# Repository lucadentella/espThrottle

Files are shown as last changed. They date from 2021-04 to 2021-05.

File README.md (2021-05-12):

# espThrottle
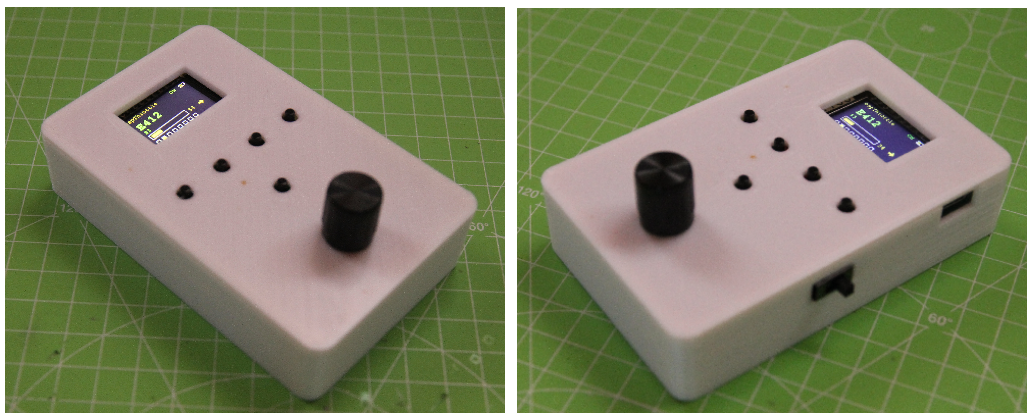
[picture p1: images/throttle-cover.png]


## Description

Portable device to control digital layouts using WiThrottle protocol.



## Features :trophy:

 - **TFT** color screen
 - **Battery** powered with built-in **USB charger**
 - Server **auto-discovery** (mDNS)
 - Configurable **favourite list** of locomotives
 - Support of JMRI **rosters**
 - Control of locomotive **speed** (128 steps) and **direction**
 - Control of 8 decoder **functions**
 - Layout **power** control
 - *Fixed address* mode

## Resources :open_file_folder:

 - [Eagle files](https://github.com/lucadentella/espThrottle/tree/main/Eagle) (schematic / PCB)
 - [Arduino firmware](https://github.com/lucadentella/espThrottle/tree/main/Arduino)
 - [3d printable case](https://github.com/lucadentella/espThrottle/tree/main/case) (STL)

## Documentation :notebook:

 - [User manual](https://github.com/lucadentella/espThrottle/tree/main/documentation/usermanual.md)
 - [Configuration manual](https://github.com/lucadentella/espThrottle/tree/main/documentation/configuration.md)
 - [How to use Roster Groups](https://github.com/lucadentella/espThrottle/tree/main/documentation/rostergroup.md)
 - [Part list](https://github.com/lucadentella/espThrottle/tree/main/documentation/partlist.md)

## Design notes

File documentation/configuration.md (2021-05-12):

# Configuration :gear:

espThrottle behavior can be configured by editing the **config.h** file:
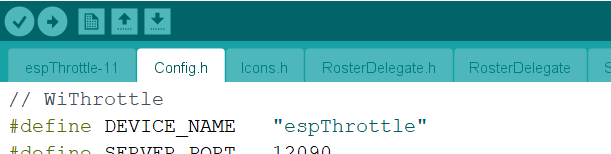
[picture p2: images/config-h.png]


## WiThrottle parameters

    #define DEVICE_NAME   "espThrottle"
    #define SERVER_PORT   12090
You can change the **device name** (i.e. the name that identifies this throttle in JMRI) and the **TCP port** the server is listening on.

## Functions

    #define ENTER_ADDRESS_ENABLED   true
    #define FAVOURITE_LIST_ENABLED  true
    #define ROSTER_LIST_ENABLED     true
    #define POWER_CONTROL_ENABLED   true
Each menu **function** can be enabled / disabled independently. 

## Fixed address mode

    #define FIXED_ADDRESS_MODE      false
The throttle can be configured in **fixed address** mode: all the menu functions (see above) are automatically disabled and the throttle controls the first locomotive of the *favourite list*.

## Speed when changing direction

    #define CHANGE_DIR_SPEED_ZERO   true
If true, when changing direction the speed is automatically set to zero. If not, the current speed is maintained.

## Favourite list

    #define FAV_LIST_ITEMS  2
    loco favLocos[FAV_LIST_ITEMS] {
      {"D345", 1234, 'L'},
      {"E412", 3, 'S'},
    };

A list of favourite locos can be configured. The list will be available in the throttle menu (if FAVOURITE_LIST_ENABLED is true, see above).

You can add as many entries as you like:

 - update the **number of entries** (FAV_LIST_ITEMS)
 - each entry contains the descriptive **name**, the DCC **address** and the address **format** (**S** for *short*, **L** for *long*).

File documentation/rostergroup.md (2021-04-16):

# JMRI roster groups

In JMRI, the list of known locos is called **Roster**. Each loco is a *Roster Entry*.
Using the **File** menu, in DecoderPro it is possible to Import/Export a single Entry or the entire Roster:

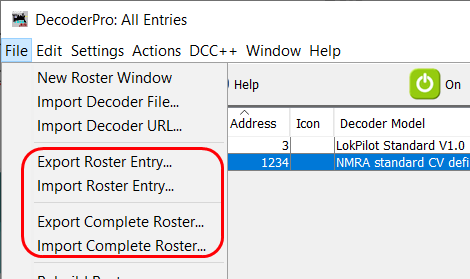
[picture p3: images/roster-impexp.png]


Roster entries can be grouped in **Roster Groups**.
First create a new Group (Settings -> **Create Roster Group**):

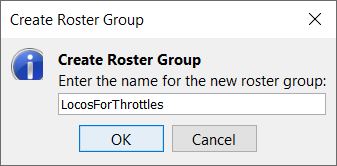
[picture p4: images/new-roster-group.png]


Then select the locos that will belong to that group (Settings -> **Roster Group Table Association**):

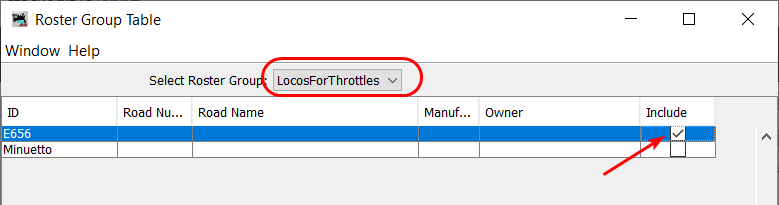
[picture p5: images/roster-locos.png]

 
A loco can belong to multiple groups.

## Throttle and Roster Groups

In the WiThrottle server configuration, you can choose which Roster Group will be available for throttles:

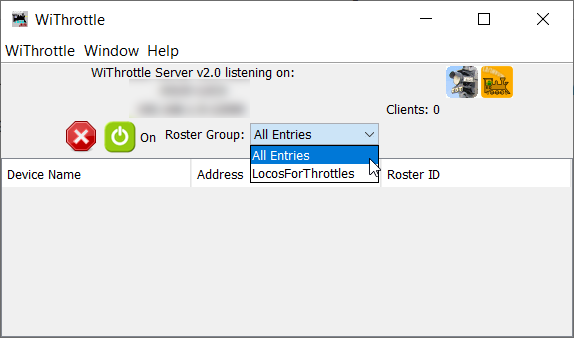
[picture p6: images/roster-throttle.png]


Locos that belong to the specified Roster Group will be visible in the throttle menu:

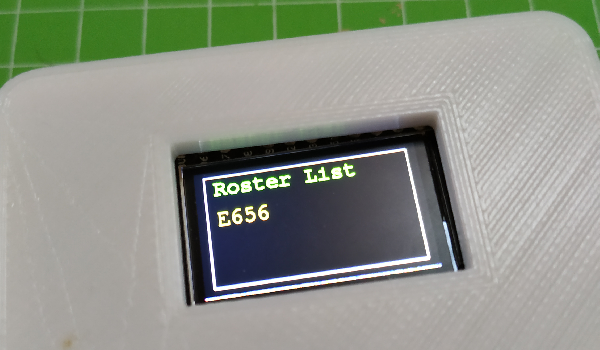
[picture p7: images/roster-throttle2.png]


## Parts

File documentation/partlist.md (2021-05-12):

# Part list :gift:
| ID | Description | 
|--|--|
| R1,R2 | Resistor, 10Kohm 1/4W |
| ENC1 | Rotary encoder |
| F0,F1,F2,F3,MENU | 6x6x15 momentary push buttons |
| TTGO | TTGO T-Display Development Board |
| PSWITCH| Angle slide switch |
| BAT | BL-5B battery |
| SCREWS | 4x 2mm self tapping screws |

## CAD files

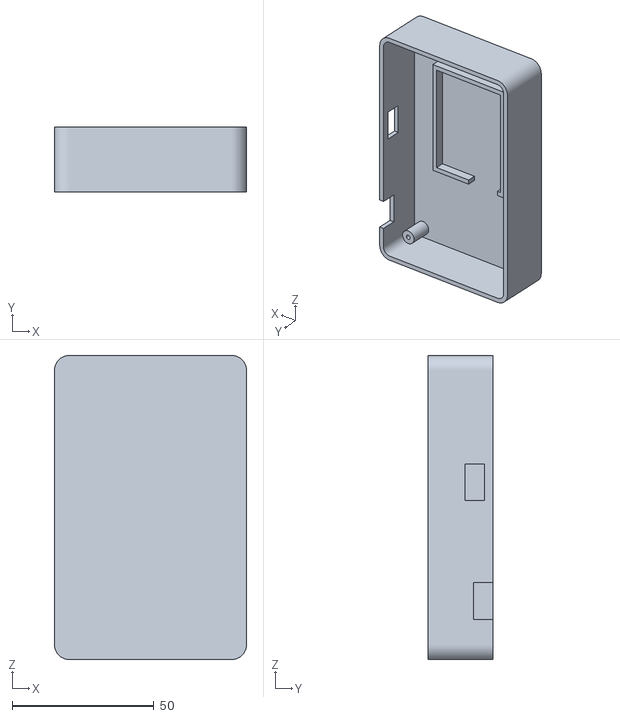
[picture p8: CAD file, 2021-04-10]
case/body.stl
67.7 x 23.0 x 107.1

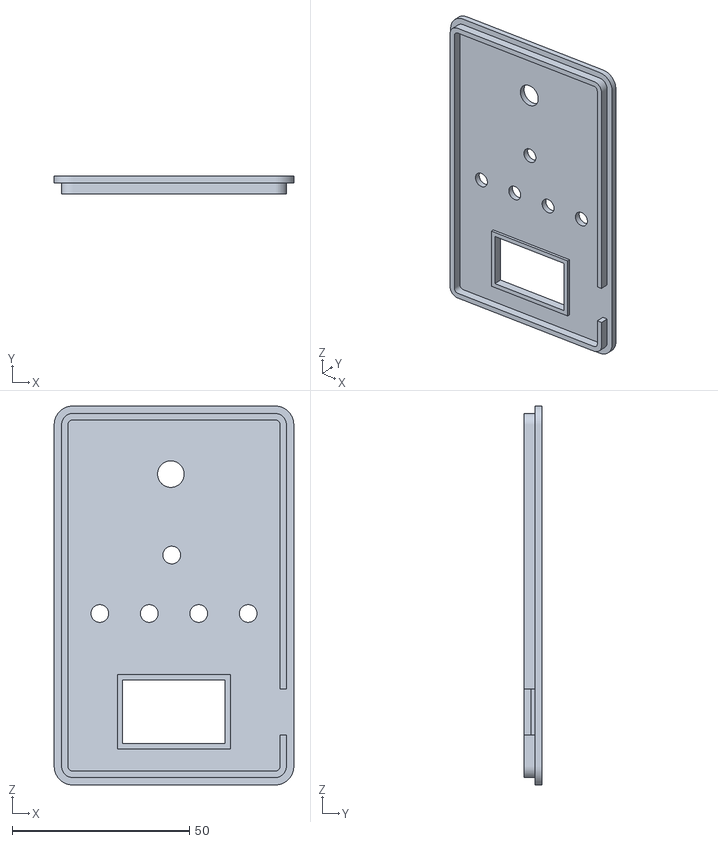
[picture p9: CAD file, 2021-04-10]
case/top.stl
67.7 x 5.00 x 107.1

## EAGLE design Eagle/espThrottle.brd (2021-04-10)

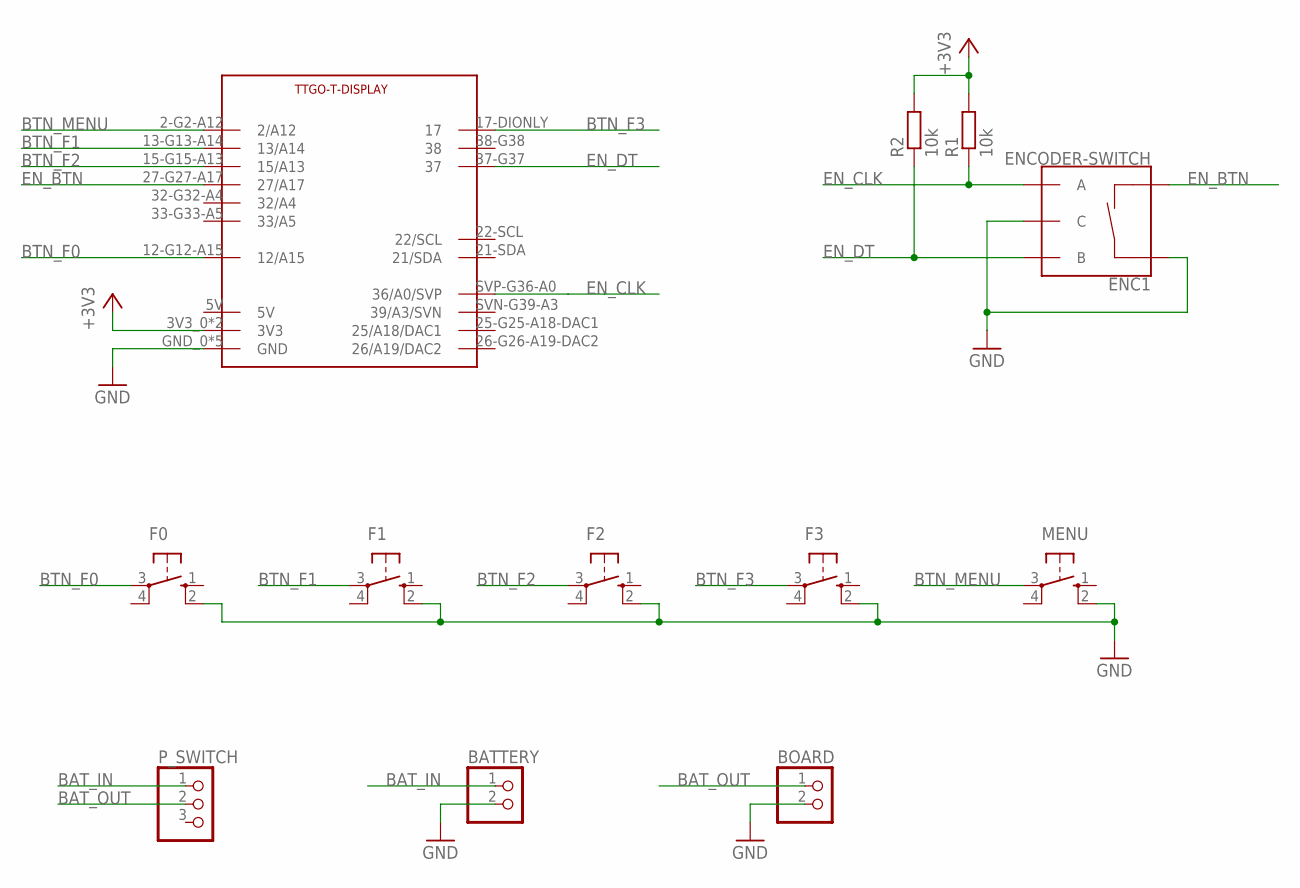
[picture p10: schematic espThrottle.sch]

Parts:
BATTERY: PINHD-1X2; 1X02
BOARD: PINHD-1X2; 1X02
ENC1: ENCODER-SWITCH; ROTARY_ENC_PLAIN
F0, F1, F2, F3: 10-XX; B3F-10XX
MENU: 10-XX; B3F-10XX
P_SWITCH: PINHD-1X3; 1X03
R1, R2: 10k; 0207/12
U$1: TTGO-T-DISPLAYFRAME; TTGO-T-DISPLAY-OL

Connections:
5V: U$1.5V
+3V3: R1.2, R2.2, U$1.3V3_0 (3V3), U$1.3V3_1 (3V3)
BAT_IN: BATTERY.1, P_SWITCH.1
BAT_OUT: BOARD.1, P_SWITCH.2
BTN_F0: F0.3, U$1.12-G12-A15 (12/A15)
BTN_F1: F1.3, U$1.13-G13-A14 (13/A14)
BTN_F2: F2.3, U$1.15-G15-A13 (15/A13)
BTN_F3: F3.3, U$1.17-DIONLY (17)
BTN_MENU: MENU.3, U$1.2-G2-A12 (2/A12)
EN_BTN: ENC1.SW-, U$1.27-G27-A17 (27/A17)
EN_CLK: ENC1.A, R1.1, U$1.SVP-G36-A0 (36/A0/SVP)
EN_DT: ENC1.B, R2.1, U$1.37-G37 (37)
GND: BATTERY.2, BOARD.2, ENC1.C, ENC1.SW+, F0.2 (S1), F1.2 (S1), F2.2 (S1), F3.2 (S1), MENU.2 (S1), U$1.GND_0 (GND), U$1.GND_1 (GND), U$1.GND_2 (GND), U$1.GND_3 (GND), U$1.GND_4 (GND)

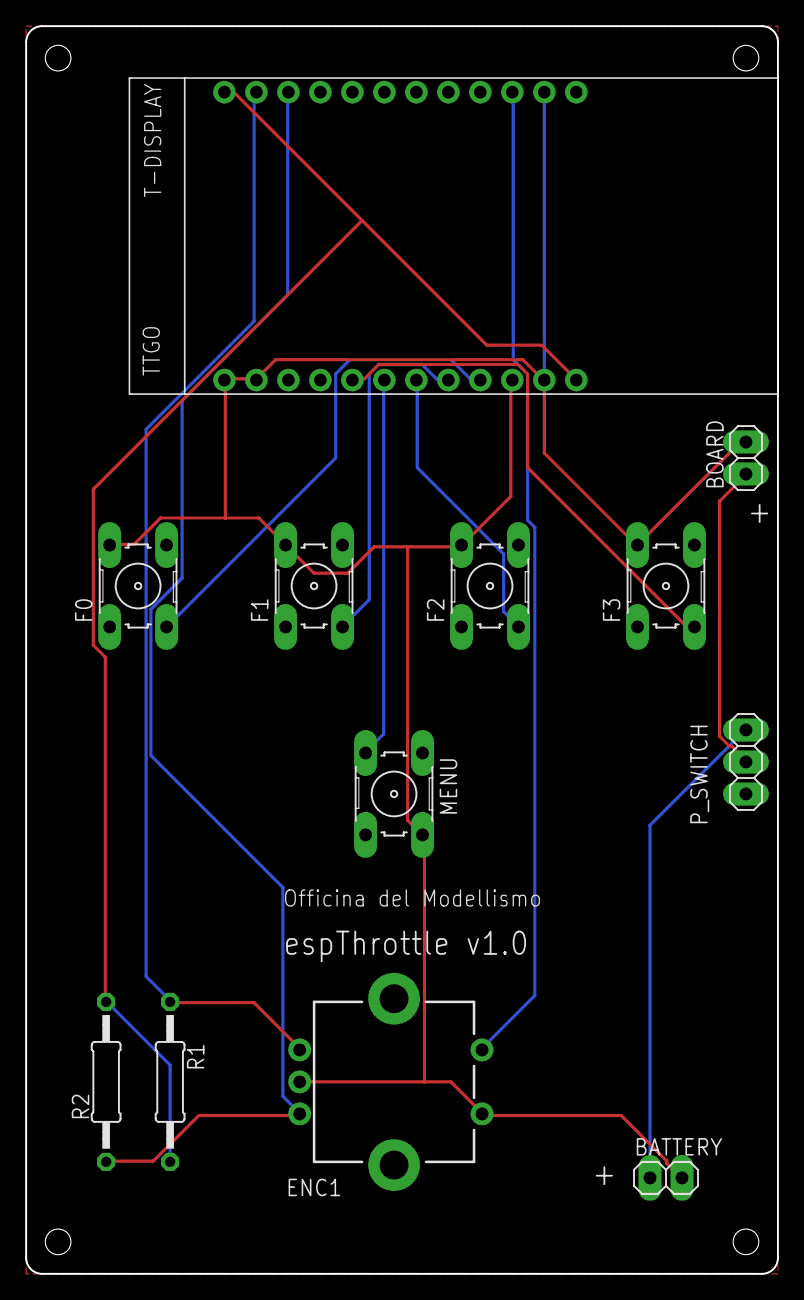
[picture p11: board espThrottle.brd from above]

Board: 2 copper layers, 59.7 x 99.1 mm, 12 parts (0 on the bottom side), 12 nets.

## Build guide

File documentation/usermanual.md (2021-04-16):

# User manual

## User controls

espThrottle has a slide switch, 5 buttons and a rotary encoder (with a pushbotton):

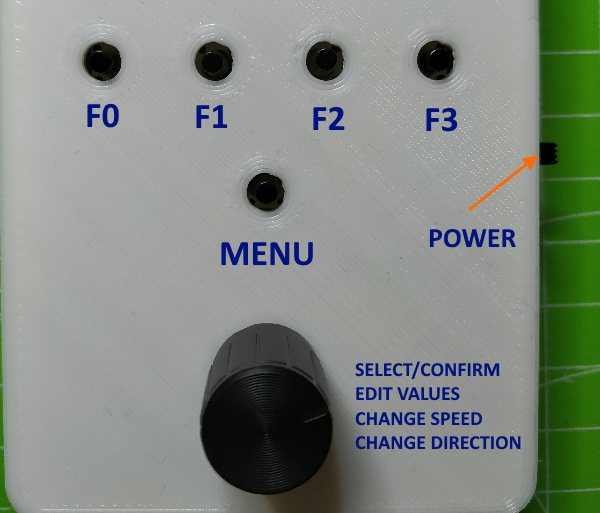
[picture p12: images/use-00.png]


## Power on and server selection

Turn on espThrottle with the slide switch.

Choose the WiThrottle server you like to connect to.
espThrottle is able to **auto-detect** running servers which broadcast their IP address via mDNS (JMRI has this feature). Otherwise you can **manually** enter the server IP address:

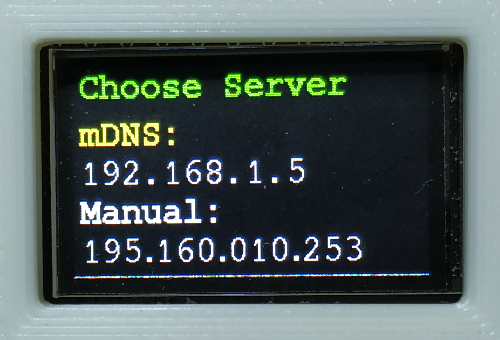
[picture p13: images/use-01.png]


By turning the rotary encoder, you can highlight (yellow) **mDNS**, **Manual** or one **octet** of the manual IP address.

If mDNS or Manual is selected and you press the encoder button, a **connection** to that server is attempted. 

If one octet is highlighted and you press the encoder button, you can **edit** the value (octet becomes red). Values can be increased/decreased by turning the rotary encoder and confirmed by pressing the encoder button again:

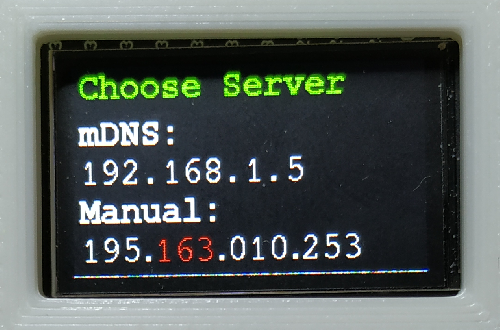
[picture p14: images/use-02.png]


## Main menu

Using the main menu you can choose **which locomotive** the throttle will control:

 - by entering the address manually
 - by selecting the loco from a favourite list
 - by selecting the loco from [JMRI roster](https://github.com/lucadentella/espThrottle/tree/main/documentation/rostergroup.md)

You can also turn the **track power** ON / OFF.

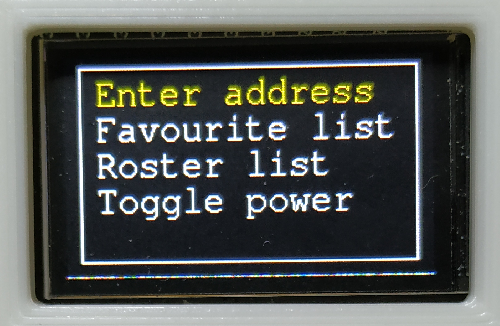
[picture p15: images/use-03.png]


One or more functions can be disabled by editing the [configuration file](https://github.com/lucadentella/espThrottle/tree/main/documentation/configuration.md). The throttle can also be put in "**fixed address** mode".

You can **open/close** the main menu pressing the corresponding button.

## Entering address

The loco address can be entered manually using the rotary encoder (similar to how the IP address is changed):

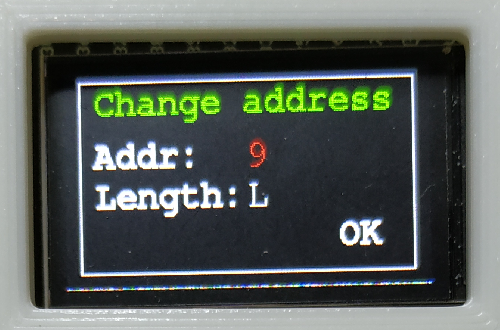
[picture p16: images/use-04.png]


When editing the address:

 - press F0 to add 10
 - press F1 to add 100
 - press F2 to substract 10
 - press F3 to substract 100

## Loco control

In the locomotive screen:

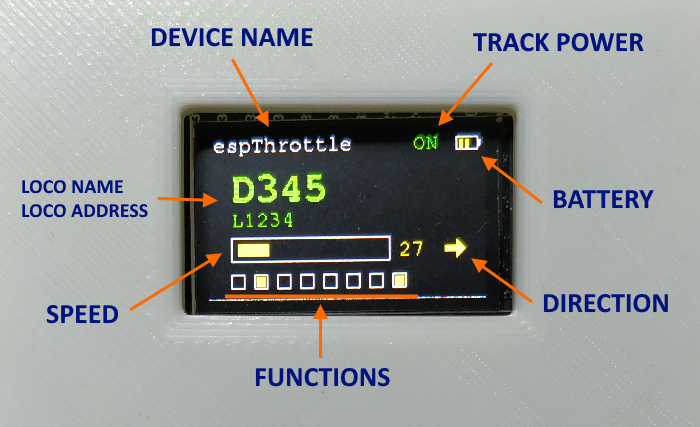
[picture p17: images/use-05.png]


 - press F0-F1-F2-F3 to turn ON/OFF the corresponding decoder **function**
 - press **MENU** + F0-F1-F2-F3 to turn ON/OFF function F4-F5-F6-F7
 - turn the rotary encoder to change the **speed**
 - press the encoder button to change the **direction**

## Battery charging

With the device **turned on**, connect a USB-C cable to the throttle.
A blue led will turn on and the battery icon on the display with change into "charging mode":

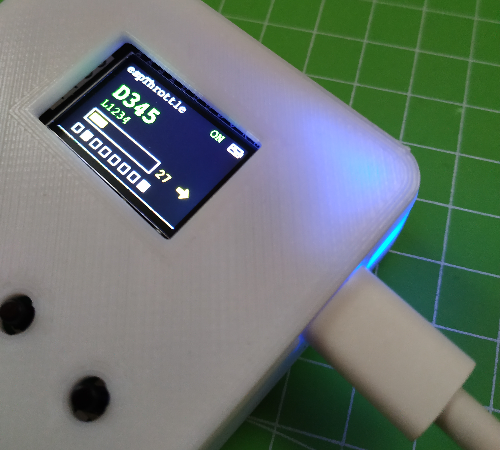
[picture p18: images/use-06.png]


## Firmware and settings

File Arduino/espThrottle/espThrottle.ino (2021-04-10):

#include "espThrottle.h"

void setup() {

  Serial.begin(115200);
  Serial.print("espThrottle v");
  Serial.println(VERSION);
  Serial.println();
  
  tft.init(TFT_HEIGHT, TFT_WIDTH);
  tft.setRotation(TFT_ROTATION);
  tft.setTextWrap(false);
  tft.setFont(&FreeMono9pt7b);
  tft.fillScreen(ST77XX_BLACK);
  pinMode(TFT_BL, OUTPUT);
  digitalWrite(TFT_BL, HIGH);
  Serial.println("Display init complete");

  encoder.attachSingleEdge(ENCODER_B, ENCODER_A);
  encoderCount = 0;
  encoder.setCount(encoderCount);
  pinMode(ENCODER_BTN, INPUT_PULLUP);
  encoderBtnPressed = false;
  Serial.println("Encoder init complete");

  initBatteryADC();
  Serial.print("ADC init complete, Vref: "); Serial.println(vref);

  for(int i = 0; i < 4; i++) 
    pinMode(fBtns[i], INPUT_PULLUP);
  pinMode(BTN_MENU, INPUT_PULLUP);
  Serial.println("Buttons init complete");

  EEPROM.begin(EEPROM_SIZE);
  Serial.println("EEPROM init complete");

  screenLoco.init(&tft, &wiThrottle);
  screenMenu.init(&tft, &wiThrottle);
  screenChangeAddr.init(&tft, &wiThrottle);
  screenList.init(&tft, &wiThrottle);
  screenServer.init(&tft, &wiThrottle);  
  currentScreen = &screenServer;
  redrawScreen = true;
  Serial.println("Screens init complete");

  wc.setAPName("espThrottle-WiFi");
  wc.setConnectionTimeoutSecs(5);
  wc.setAPCallback(configModeCallback);  
  Serial.println("WiFiManager init complete");
  Serial.println();
  
  if (!wc.autoConnect()) {
      wc.startConfigurationPortal(AP_LOOP);
  }
  Serial.println("Connected to WiFi");
}

void loop() {

  // screen refresh required
  if(redrawScreen) {
    currentScreen->show();
    redrawScreen = false;
  }

  currentScreen->run();
  wiThrottle.check();

  // check encoder position
  int64_t newEncoderCount = encoder.getCount(); 
  if(newEncoderCount != encoderCount) {
    bool forward = (newEncoderCount > encoderCount) ? true : false;
    currentScreen->encoderTick(forward);
    encoderCount = newEncoderCount;
  }

  // check encoder button
  int encoderButtonStatus = digitalRead(ENCODER_BTN);
  if(encoderButtonStatus == HIGH) {
    if(encoderBtnPressed) {
      currentScreen->encoderClick();
    }
    encoderBtnPressed = false;
  }
  else encoderBtnPressed = true;

  // check fButton 
  int buttonMenuStatus = digitalRead(BTN_MENU);
  
  for(int i = 0; i < 4; i++) {
    
    int fButtonStatus = digitalRead(fBtns[i]);
    
    // button pressed
    if(fButtonStatus == LOW) {
      
      // button wasn't already pressed
      if(!fBtnsPressed[i]) {
        currentScreen->fBtnChange(i, true, !buttonMenuStatus);
        fBtnsPressed[i] = true;
        discardMenuBtn = true;
      }      
    }
    
    // button released
    else {

        // button was pressed
      if(fBtnsPressed[i]) {
        currentScreen->fBtnChange(i, false, !buttonMenuStatus);
        fBtnsPressed[i] = false;
       }
    }
  }

  // check menu button
  if(buttonMenuStatus == HIGH && menuBtnPressed) {
    if(!discardMenuBtn) currentScreen->menuClick();
    else discardMenuBtn = false;
    menuBtnPressed = false;
  }
  if(buttonMenuStatus == LOW && !menuBtnPressed) menuBtnPressed = true;
}

void configModeCallback(WiFiConnect *mWiFiConnect) {
  
  Serial.println("No WiFi configured or available, entering AP mode...");
  tft.drawBitmap(70, 17, wifisetup, 100, 100, ST77XX_WHITE);
}

void initBatteryADC() {
  
  esp_adc_cal_characteristics_t adc_chars;
  esp_adc_cal_value_t val_type = esp_adc_cal_characterize((adc_unit_t)ADC_UNIT_1, (adc_atten_t)ADC1_CHANNEL_6, (adc_bits_width_t)ADC_WIDTH_BIT_12, 1100, &adc_chars);
  if(val_type == ESP_ADC_CAL_VAL_EFUSE_VREF) vref = adc_chars.vref;
}

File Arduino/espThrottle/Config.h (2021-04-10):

// WiThrottle
#define DEVICE_NAME   "espThrottle"
#define SERVER_PORT   12090

// When changing direction, set speed to zero
#define CHANGE_DIR_SPEED_ZERO   true

// Enable/Disable functions
#define ENTER_ADDRESS_ENABLED   true
#define FAVOURITE_LIST_ENABLED  true
#define ROSTER_LIST_ENABLED     true
#define POWER_CONTROL_ENABLED   true

// Fixed address mode:
// uses the first address in the Favourite List
// and disables the menu
#define FIXED_ADDRESS_MODE      false

// Favourite list
#define FAV_LIST_ITEMS  2
loco favLocos[FAV_LIST_ITEMS] {
  {"D345", 1234, 'L'},
  {"E412", 3, 'S'},
};

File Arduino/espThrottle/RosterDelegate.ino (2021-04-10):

void RosterDelegate::receivedTrackPower(TrackPower state) {

  trackPower = state;
}

void RosterDelegate::receivedRosterEntries(int rosterSize) {     

  if(rosterSize > MAX_ROSTER_ENTRIES) rosterLocosNum = MAX_ROSTER_ENTRIES;
  else rosterLocosNum = rosterSize;
}
  
void RosterDelegate::receivedRosterEntry(int index, String name, int address, char length) {

  if(index < MAX_ROSTER_ENTRIES) {
    rosterLocos[index].locoName = name;
    rosterLocos[index].locoAddress = address;
    rosterLocos[index].locoAddressLength = length;
  }
}

int RosterDelegate::getRosterLocosNum() {

  return rosterLocosNum;
}

loco* RosterDelegate::getRosterLocos() {

  return rosterLocos;
}

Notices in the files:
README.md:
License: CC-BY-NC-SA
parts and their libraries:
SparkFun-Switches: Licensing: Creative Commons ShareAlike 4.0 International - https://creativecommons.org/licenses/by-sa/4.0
